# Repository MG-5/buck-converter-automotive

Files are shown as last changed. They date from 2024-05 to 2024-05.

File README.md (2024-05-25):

# buck-converter-automotive
12V to 5V 1A buck converter to automotive purposes

### Requirements for rev 1.0
* efficient step-down synchronous converter
* fuse
* TVS diodes
* reverse polarity protection
* LC input filter
* power-on LED

### Pictures (rev 1.0)

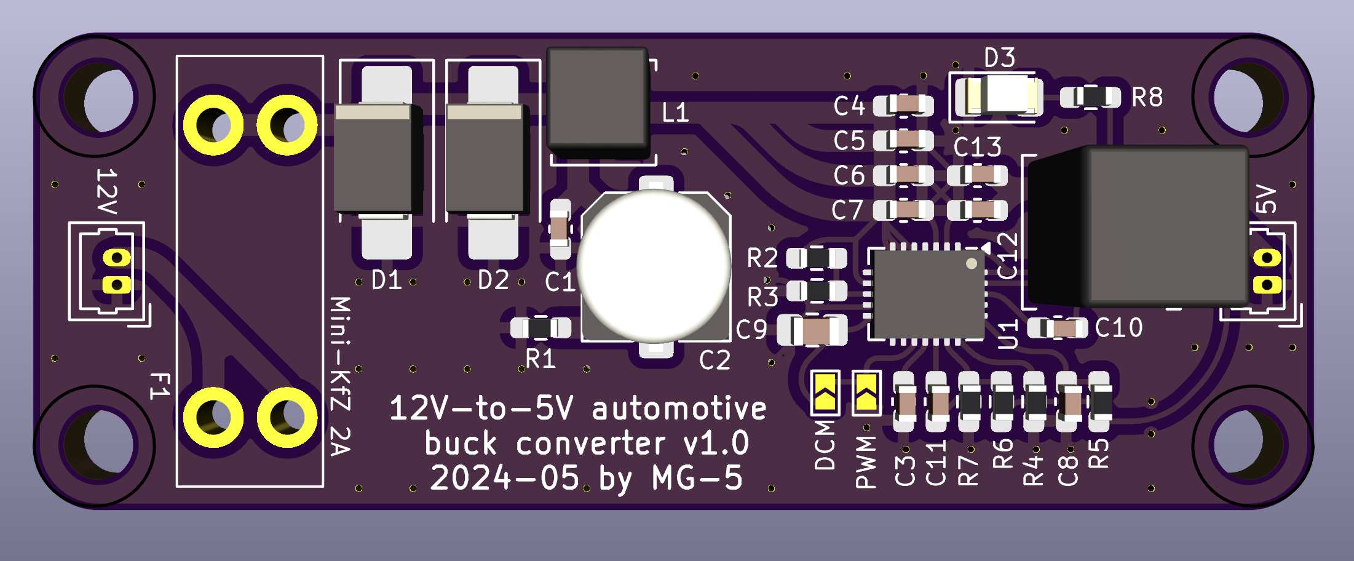
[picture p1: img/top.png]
pcb top PCB v1.0 top view


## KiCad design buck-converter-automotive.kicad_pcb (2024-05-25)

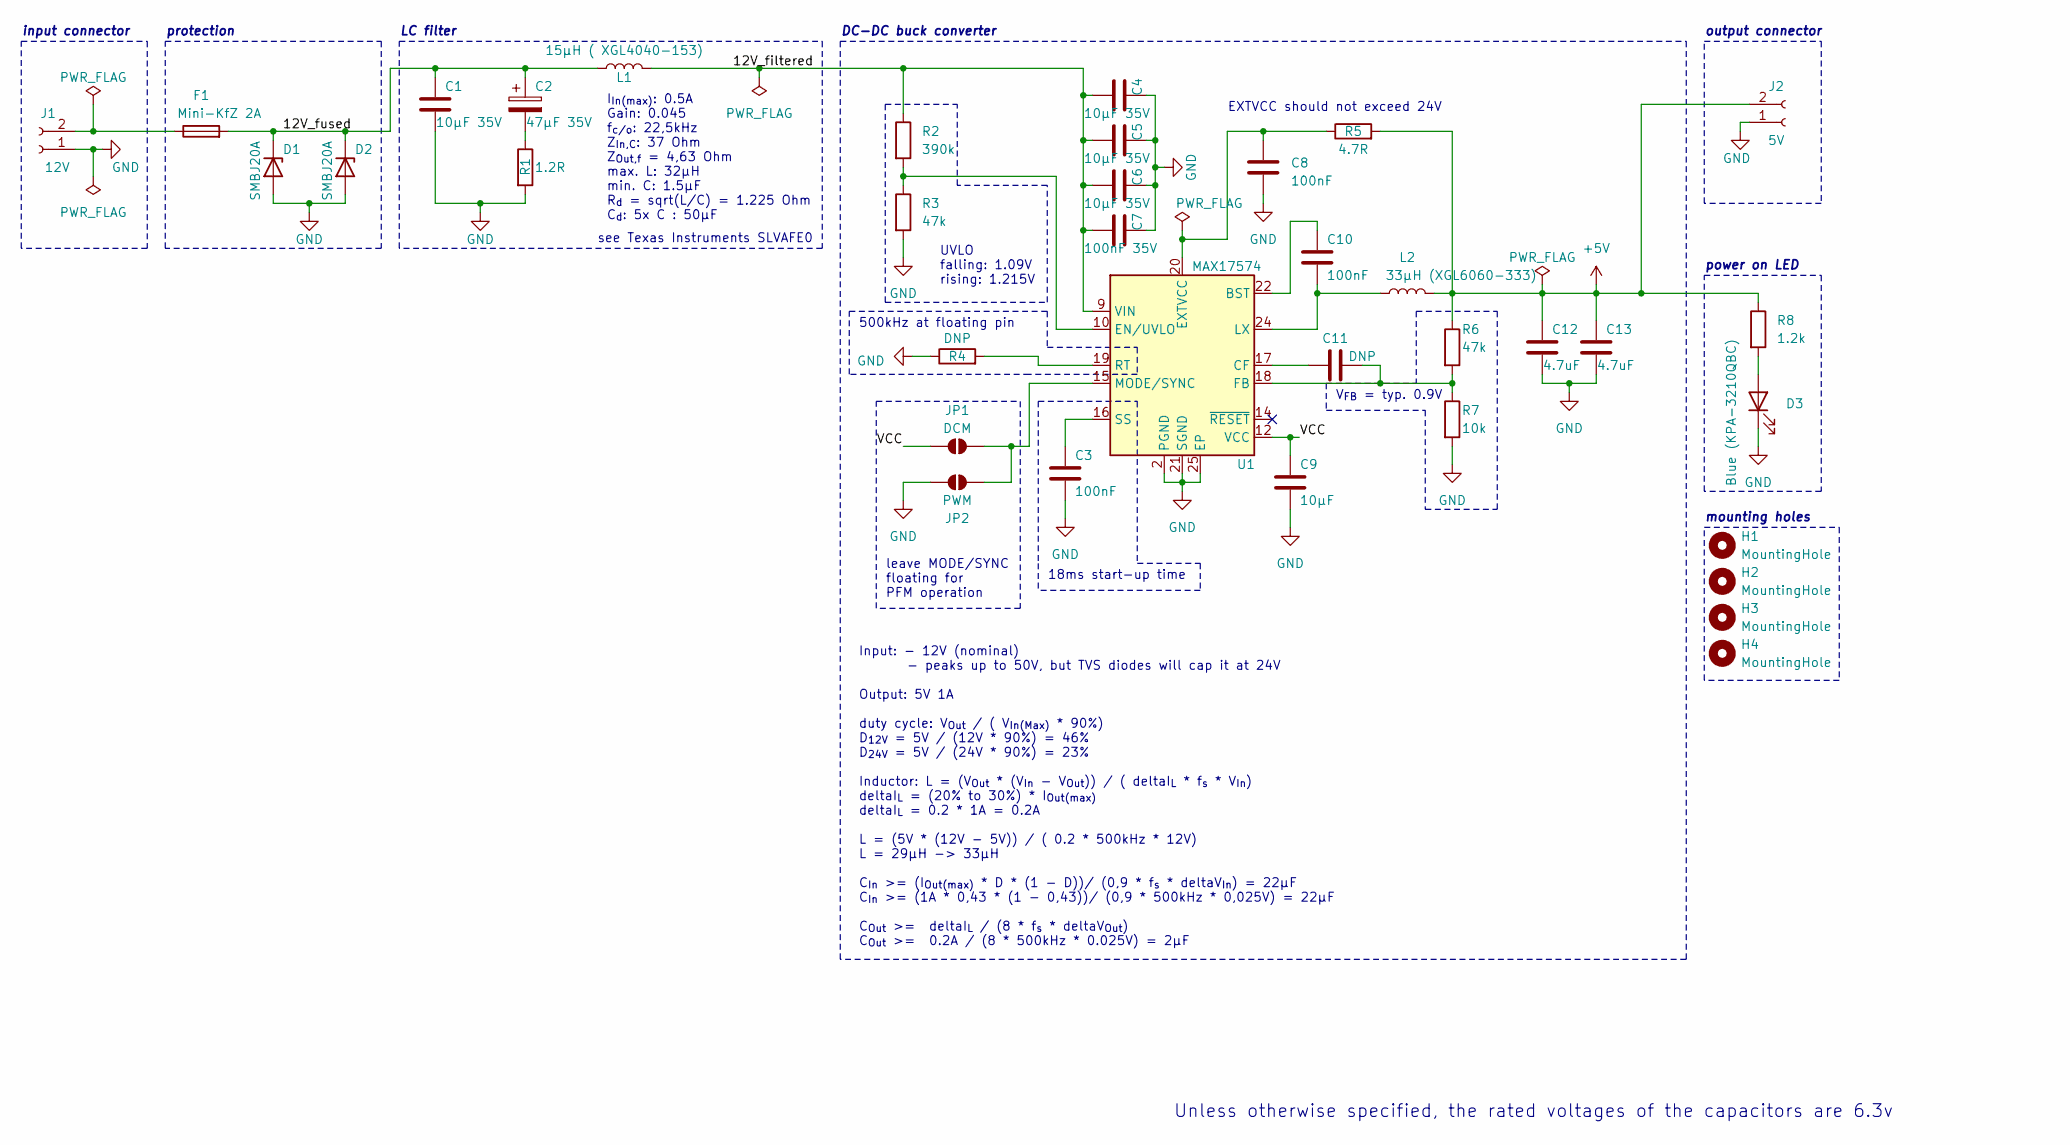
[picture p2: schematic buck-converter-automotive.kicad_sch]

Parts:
C1, C4, C5, C6: 10µF 35V; C_0603_1608Metric_Pad1.08x0.95mm_HandSolder
C2: 47µF 35V; C_Elec_6.3x5.8
C3, C8, C10: 100nF; C_0603_1608Metric_Pad1.08x0.95mm_HandSolder
C7: 100nF 35V; C_0603_1608Metric_Pad1.08x0.95mm_HandSolder
C9: 10µF; C_0805_2012Metric_Pad1.18x1.45mm_HandSolder
C11: DNP; C_0603_1608Metric_Pad1.08x0.95mm_HandSolder
C12, C13: 4.7uF; C_0603_1608Metric_Pad1.08x0.95mm_HandSolder
D1, D2: SMBJ20A; D_SMB_Handsoldering
D3: Blue (KPA-3210QBC); LED_1206_3216Metric
F1: Mini-KfZ 2A; KEYSTONE-FUSE-3557-2
H1, H2, H3, H4: MountingHole; MountingHole_3.2mm_M3_ISO14580
J1: 12V; Molex_PicoBlade_53047-0210_1x02_P1.25mm_Vertical
J2: 5V; Molex_PicoBlade_53047-0210_1x02_P1.25mm_Vertical
JP1: DCM; SolderJumper-Open_0603
JP2: PWM; SolderJumper-Open_0603
L1: 15µH ( XGL4040-153); L_Coilcraft_XAL4040-XXX
L2: 33µH (XGL6060-333); L_Coilcraft_XAL6060-XXX
R1: 1.2R; R_0603_1608Metric_Pad0.98x0.95mm_HandSolder
R2: 390k; R_0603_1608Metric_Pad0.98x0.95mm_HandSolder
R3, R6: 47k; R_0603_1608Metric_Pad0.98x0.95mm_HandSolder
R4: DNP; R_0603_1608Metric_Pad0.98x0.95mm_HandSolder
R5: 4.7R; R_0603_1608Metric_Pad0.98x0.95mm_HandSolder
R7: 10k; R_0603_1608Metric_Pad0.98x0.95mm_HandSolder
R8: 1.2k; R_0603_1608Metric_Pad0.98x0.95mm_HandSolder
U1: MAX17574; QFN-24-1EP_4x5mm_P0.5mm_EP2.65x3.65mm

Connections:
+5V: C12.2, C13.2, J2.2, L2.2, R5.2, R6.1, R8.1
/12V_filtered: C4.1, C5.1, C6.1, C7.1, L1.2, R2.1, U1.5 (VIN), U1.6 (VIN), U1.7 (VIN), U1.9 (VIN)
/12V_fused: C1.1, C2.1, D1.1 (K), D2.1 (K), F1.2, L1.1
/VCC: C9.1, JP1.1 (A), U1.12 (VCC)
GND: C1.2, C3.2, C4.2, C5.2, C6.2, C7.2, C8.1, C9.2, C12.1, C13.1, D1.2 (A), D2.2 (A), D3.1 (K), J1.1, J2.1, JP2.1 (A), R1.2, R3.2, R4.1, R7.2, U1.2 (PGND), U1.3 (PGND), U1.11 (PGND), U1.21 (SGND), U1.25 (EP)
unnamed: C2.2, R1.1
unnamed: C10.1, L2.1, U1.1 (LX), U1.23 (LX), U1.24 (LX)
unnamed: D3.2 (A), R8.2
unnamed: F1.1, J1.2
unnamed: JP1.2 (B), JP2.2 (B), U1.15 (MODE/SYNC)
unnamed: C10.2, U1.22 (BST)
unnamed: C11.1, U1.17 (CF)
unnamed: R2.2, R3.1, U1.10 (EN/UVLO)
unnamed: C8.2, R5.1, U1.20 (EXTVCC)
unnamed: C11.2, R6.2, R7.1, U1.18 (FB)
unnamed: R4.2, U1.19 (RT)
unnamed: C3.1, U1.16 (SS)

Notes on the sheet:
power on LED
DC-DC buck converter
leave MODE/SYNC floating for PFM operation
I_{In(max)}: 0.5A Gain: 0.045 f_{c/o}: 22,5kHz Z_{In,C}: 37 Ohm Z_{Out,f} = 4,63 Ohm max. L: 32µH min. C: 1.5µF R_{d} = sqrt(L/C) = 1.225 Ohm C_{d}: 5x C : 50µF
UVLO falling: 1.09V rising: 1.215V
LC filter
input connector
500kHz at floating pin
protection
Unless otherwise specified, the rated voltages of the capacitors are 6.3v
EXTVCC should not exceed 24V
see Texas Instruments SLVAFE0
18ms start-up time
Input: - 12V (nominal) - peaks up to 50V, but TVS diodes will cap it at 24V Output: 5V 1A duty cycle: V_{Out} / ( V_{In(Max)} * 90%) D_{12V} = 5V / (12V * 90%) = 46% D_{24V} = 5V / (24V * 90%) = 23% Inductor: L = (V_{Out} * (V_{In} - V_{Out})) / ( deltaI_{L} * f_{s} * V_{In}) deltaI_{L} = (20% to 3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
mounting holes
output connector
V_{FB} = typ. 0.9V

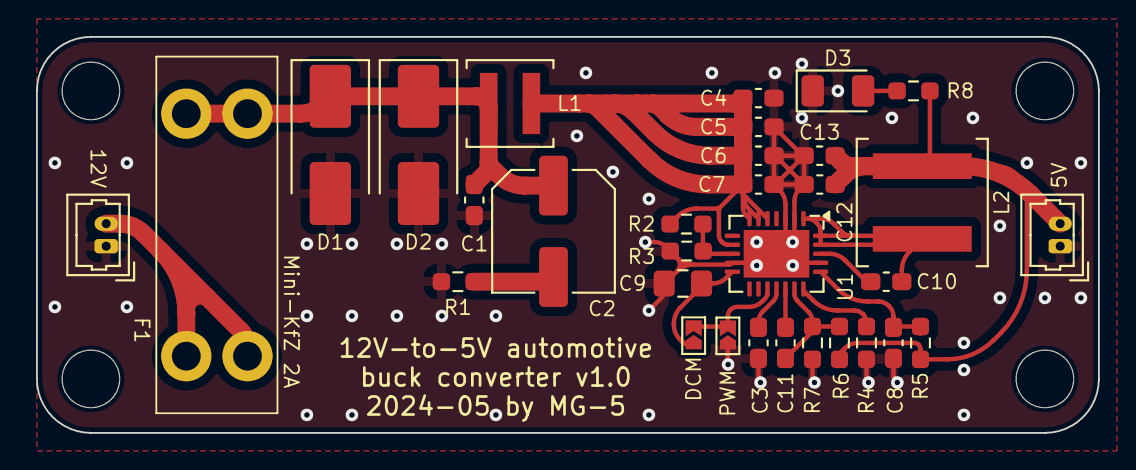
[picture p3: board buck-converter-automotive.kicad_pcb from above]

Board: 2 copper layers, 59.0 x 22.0 mm, 36 parts (0 on the bottom side), 17 nets.

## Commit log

2024-05-25 Init project Add schematic Add PCB
    [buck-converter-automotive.kicad_pcb, buck-converter-automotive.kicad_sch]
2024-07-10 Make some parts as DNP
    [buck-converter-automotive.kicad_sch]
